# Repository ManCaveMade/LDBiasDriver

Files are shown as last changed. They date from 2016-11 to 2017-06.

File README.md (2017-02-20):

## LDBiasDriver
Copyright Mitchell A. Cox (mitch@enox.co.za)

If you use this design, please acknowledge me in any resulting publications.

### What is it?

1. A low noise laser diode bias driver which uses the ThorLabs MLD203P1 constant power and also the MLD203CLN constanct current (better for fast modulation systems which use a Bias-Tee) bias driver. https://www.thorlabs.com/thorproduct.cfm?partnumber=MLD203P1 and https://www.thorlabs.com/thorproduct.cfm?partnumber=MLD203CLN

2. An Arduino based controller for the CC version is WIP. This controller will allow greater than 12 bits of control of the output current as well as digital monitoring of the actual current, etc. I also plan on creating a user friendly MATLAB GUI for it.

#### Features

* Input voltage: 6 - 18 V
* Output current: < 200 mA @ 3.0 V
* Laser current monitor output: 0.1V/mA wrt. GND (can be changed by changing resistors on op-amp)
* Over current protection resistor (R3)
* Sexy red power on LED
* Compact
* SMA for DC bias output (easy connection direct to Bias-Tee)
* ~3 uA noise
 
Designed with Eagle 7.7

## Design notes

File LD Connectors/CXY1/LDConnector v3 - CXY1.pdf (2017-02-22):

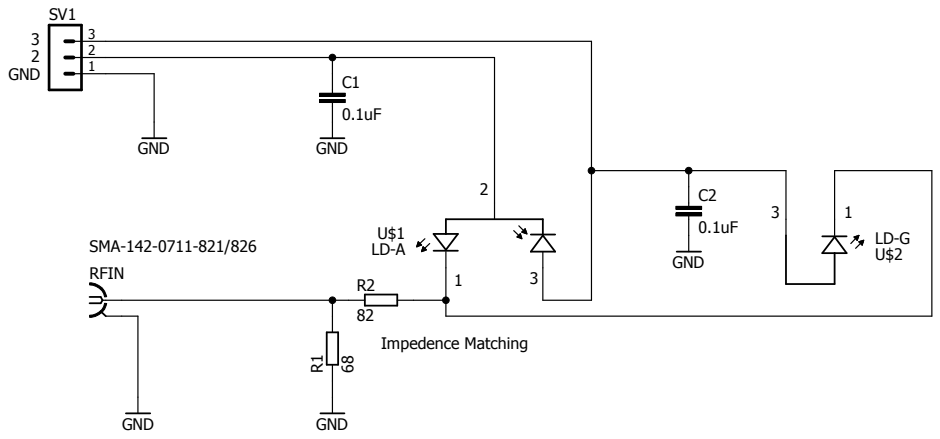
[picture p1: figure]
GND; SMA-142-0711-821/826; GND ⁶⁸; GND RFIN; Impedence Matching

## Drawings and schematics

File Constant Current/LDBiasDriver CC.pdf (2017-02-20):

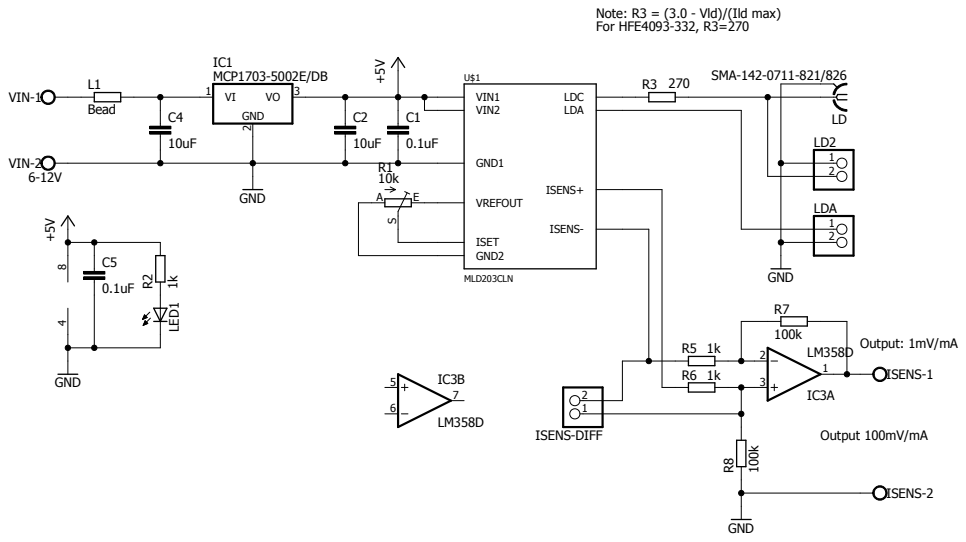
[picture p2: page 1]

Note: R3 = (3.0 - Vld)/(Ild max)
For HFE4093-332, R3=270

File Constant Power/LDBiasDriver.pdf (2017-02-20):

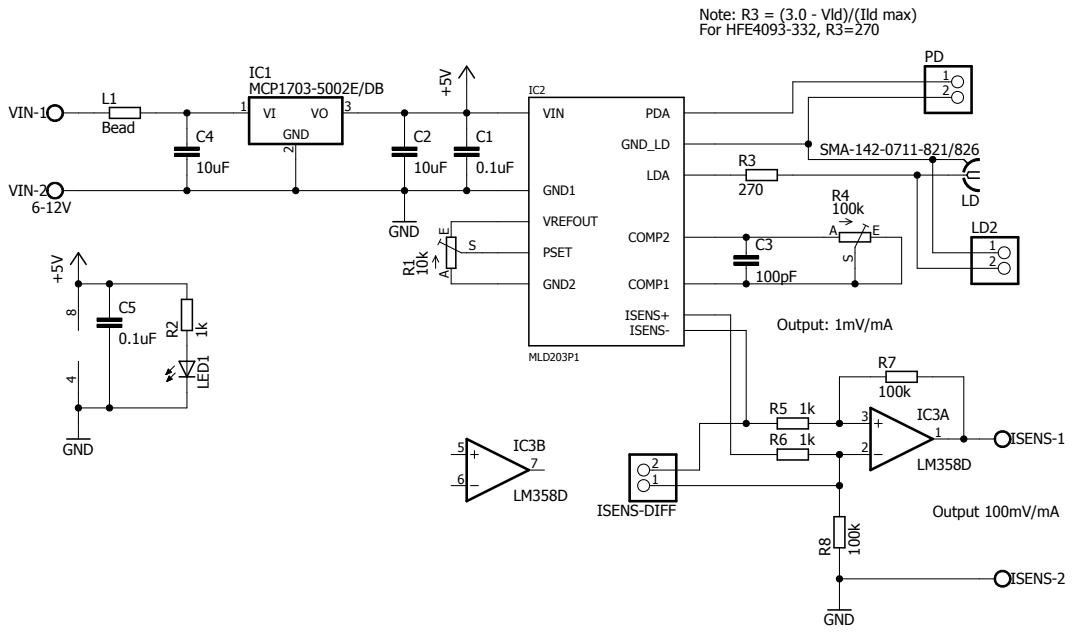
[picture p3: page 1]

Note: R3 = (3.0 - Vld)/(Ild max)
For HFE4093-332, R3=270

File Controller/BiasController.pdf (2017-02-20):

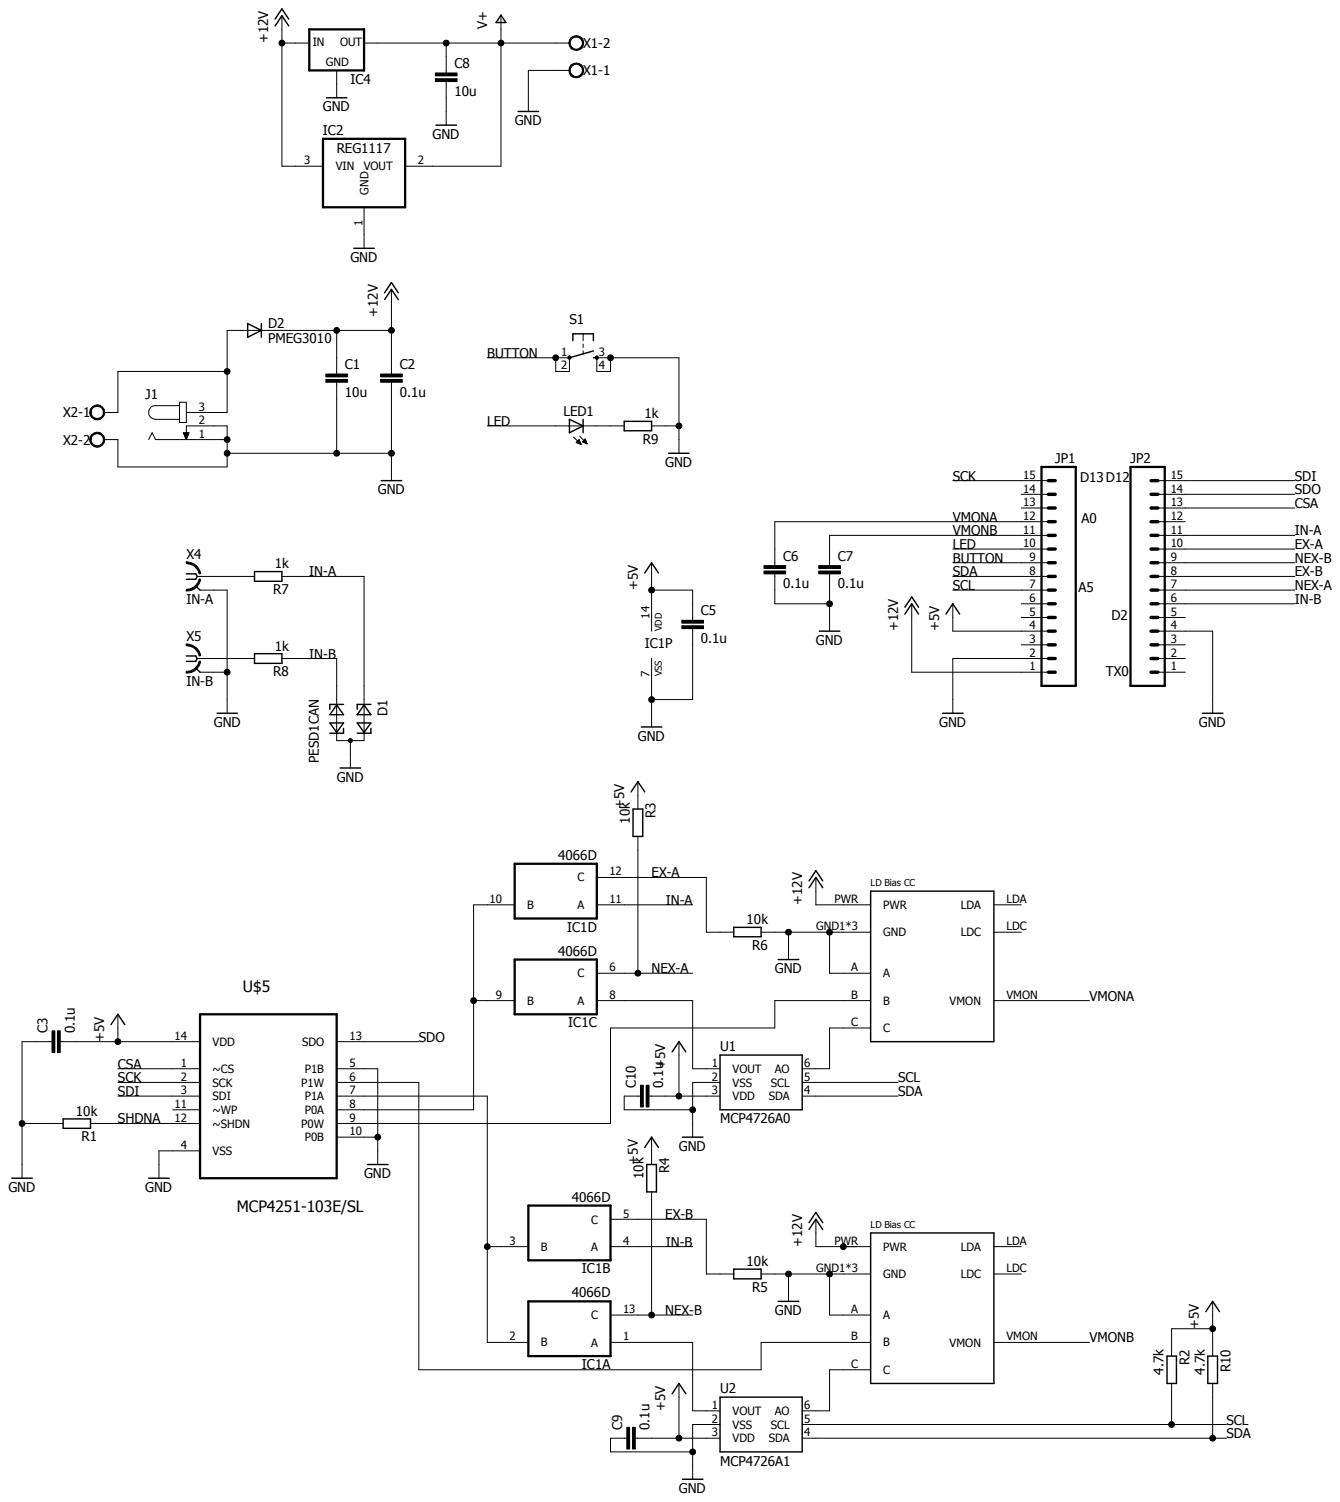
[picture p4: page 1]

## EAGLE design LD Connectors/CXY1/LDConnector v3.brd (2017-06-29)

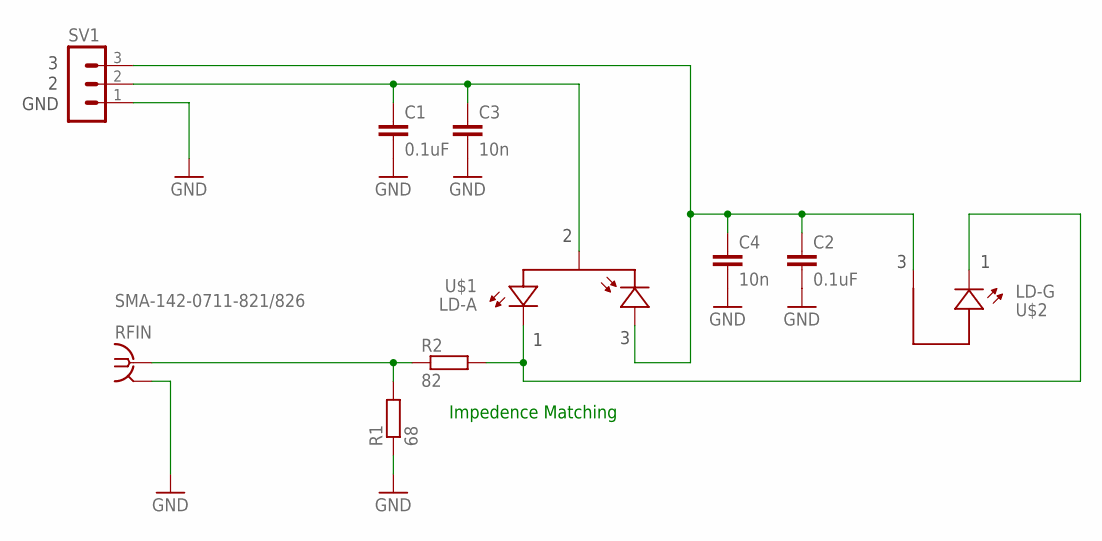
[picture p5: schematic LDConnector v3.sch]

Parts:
C1, C2: 0.1uF; C0603
C3, C4: 10n; C0603
R1: 68; R0603
R2: 82; R0603
RFIN: SMA-142-0711-821/826; J502-ND-142-0711-821/826
SV1: MA03-1
U$1: LD-A; TYPEA
U$2: LD-G; TYPEG

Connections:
GND: C1.2, C2.2, C3.2, C4.2, R1.1, RFIN.G@1 (2), RFIN.G@2 (2), RFIN.G@3 (2), RFIN.G@4 (2), SV1.1
unnamed: C1.1, C3.1, SV1.2, U$1.2-PDC-LDA (LDA-PDC)
unnamed: R2.2, U$1.1-LDC (LDC), U$2.1-LDC (LDC)
unnamed: R1.2, R2.1, RFIN.1
unnamed: C2.1, C4.1, SV1.3, U$1.3-PDA (PDA), U$2.3-LDA (LDA)

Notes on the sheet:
Impedence Matching
GND

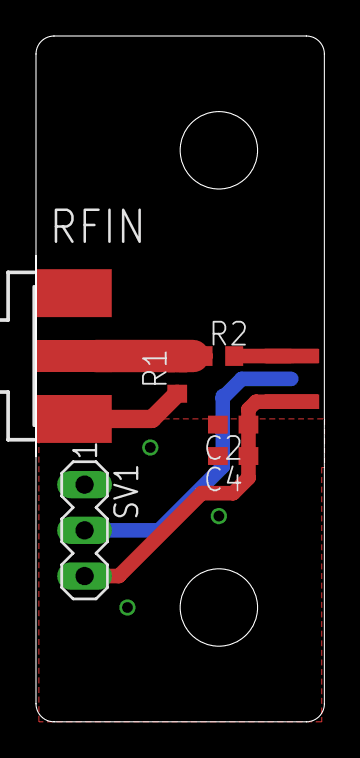
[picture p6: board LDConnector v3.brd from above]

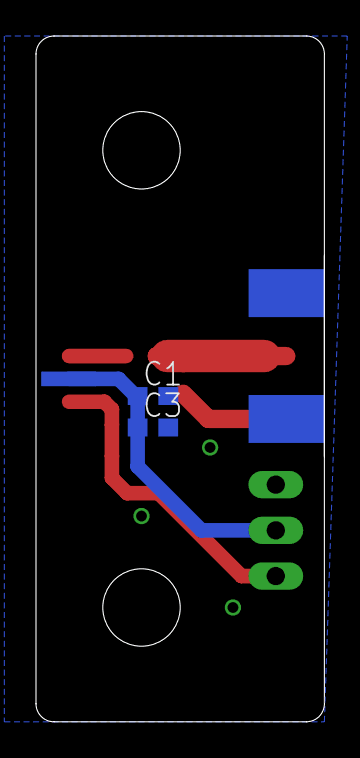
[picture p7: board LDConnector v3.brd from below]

Board: 2 copper layers, 16.0 x 38.1 mm, 10 parts (2 on the bottom side), 5 nets.

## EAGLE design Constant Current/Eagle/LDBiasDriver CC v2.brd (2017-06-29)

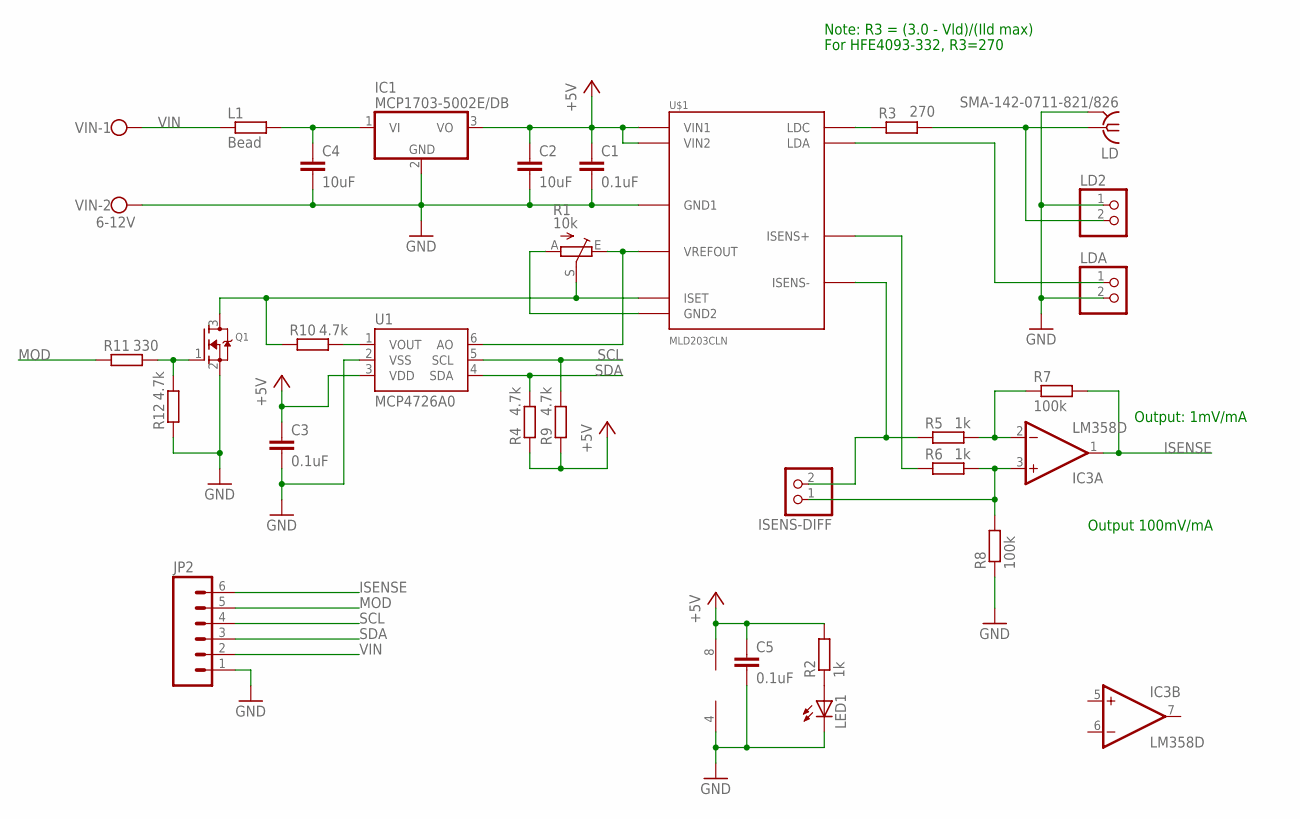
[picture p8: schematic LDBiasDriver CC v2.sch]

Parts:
C1, C3, C5: 0.1uF; C0805
C2, C4: 10uF; C0805
IC1: MCP1703-5002E/DB; SOT223
IC3: LM358D; SO08
ISENS-DIFF: PINHD-1X2; 1X02
JP2: M06POLAR_LOCK; MOLEX-1X6_LOCK
L1: Bead; R0805
LD: SMA-142-0711-821/826; J502-ND-142-0711-821/826
LD2: PINHD-1X2; 1X02
LDA: PINHD-1X2; 1X02
LED1: LEDCHIPLED_1206; CHIPLED_1206
Q1: MOSFET-NREFLOW; SOT23
R1: 10k; RJ9W
R2, R5, R6: 1k; R0805
R3: 270; R0805
R4, R9, R10, R12: 4.7k; R0805
R7, R8: 100k; R0805
R11: 330; R0805
U1: MCP4726A0; SOT23-6
U$1: MLD203CLN; MLD203
VIN: 6-12V; W237-102

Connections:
+5V: C1.1, C2.1, C3.1, C5.1, IC1.3 (VO), IC3.8 (V+), R2.2, R4.1, R9.1, U1.3 (VDD), U$1.P$1 (VIN1), U$1.P$2 (VIN2)
GND: C1.2, C2.2, C3.2, C4.2, C5.2, IC1.2 (GND), IC3.4 (V-), JP2.1, LD.G@1 (2), LD.G@2 (2), LD.G@3 (2), LD.G@4 (2), LD2.1, LDA.2, LED1.C, Q1.2 (S), R8.1, R12.1, U1.2 (VSS), U$1.P$3 (GND1), VIN.2
ISENSE: IC3.1 (OUT), JP2.6, R7.2
MOD: JP2.5, R11.1
unnamed: R1.E, U1.6 (AO), U$1.P$5 (VREFOUT)
unnamed: LED1.A, R2.1
unnamed: Q1.3 (D), R1.S, R10.1, U$1.P$6 (ISET)
unnamed: R1.A, U$1.P$4 (GND2)
unnamed: R6.1, U$1.P$12 (ISENS+)
unnamed: ISENS-DIFF.2, R5.1, U$1.P$13 (ISENS-)
unnamed: LD.1, LD2.2, R3.2
unnamed: R3.1, U$1.P$11 (LDC)
unnamed: Q1.1 (G), R11.2, R12.2
unnamed: LDA.1, U$1.P$14 (LDA)
unnamed: R10.2, U1.1 (VOUT)
unnamed: C4.1, IC1.1 (VI), L1.2
unnamed: IC3.2 (-IN), R5.2, R7.1
unnamed: IC3.3 (+IN), ISENS-DIFF.1, R6.2, R8.2
SCL: JP2.4, R9.2, U1.5 (SCL)
SDA: JP2.3, R4.2, U1.4 (SDA)
VIN: JP2.2, L1.1, VIN.1

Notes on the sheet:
Note: R3 = (3.0 - Vld)/(Ild max)
For HFE4093-332, R3=270
Output: 1mV/mA
Output 100mV/mA

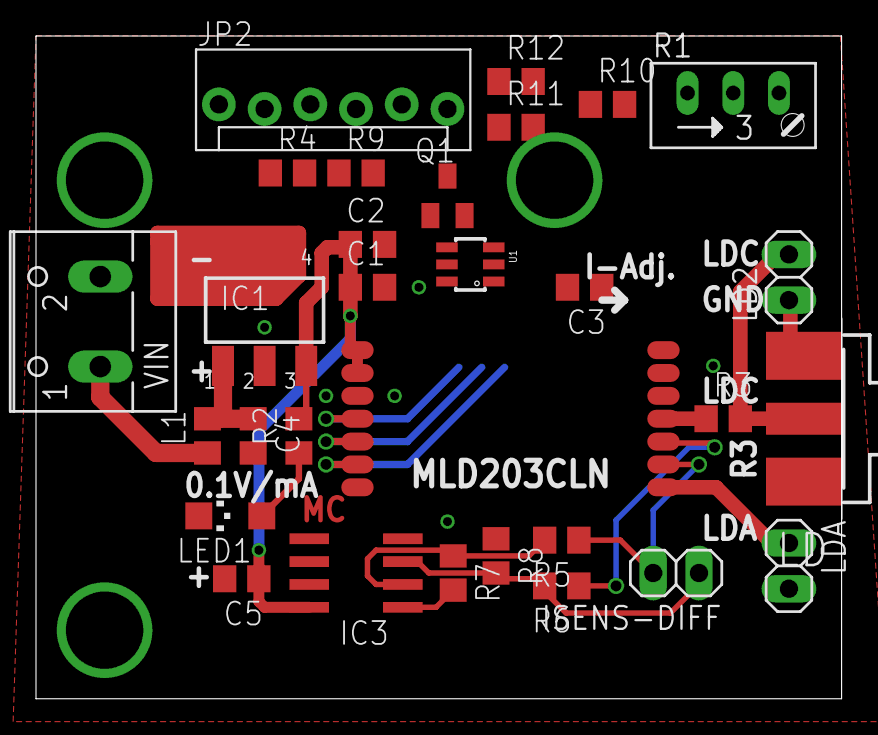
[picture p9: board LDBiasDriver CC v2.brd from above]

Board: 2 copper layers, 44.8 x 36.8 mm, 30 parts (0 on the bottom side), 21 nets.

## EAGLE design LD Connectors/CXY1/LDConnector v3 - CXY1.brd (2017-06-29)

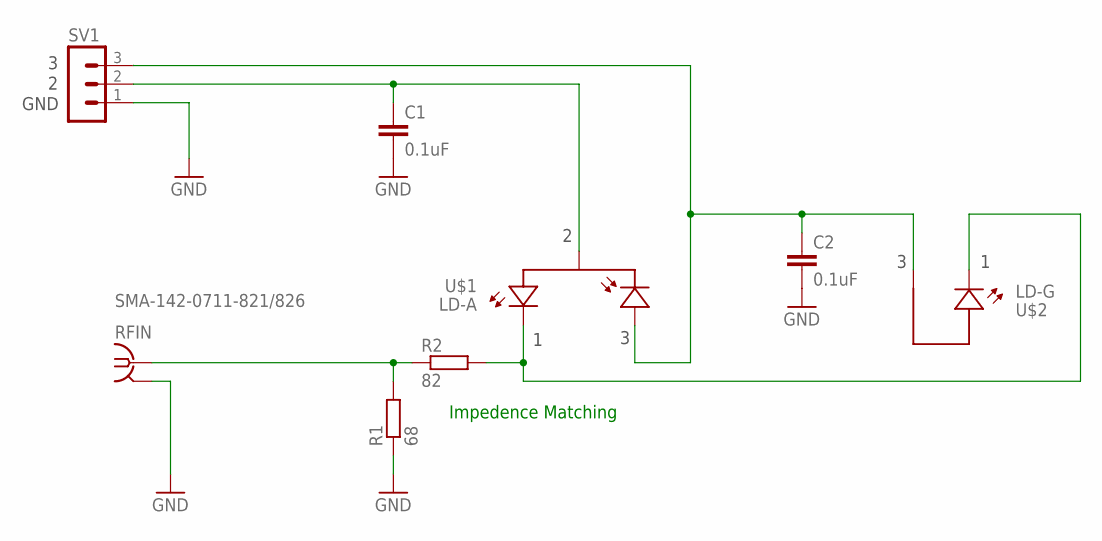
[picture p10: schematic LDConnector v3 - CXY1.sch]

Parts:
C1, C2: 0.1uF; C0603
R1: 68; R0603
R2: 82; R0603
RFIN: SMA-142-0711-821/826; J502-ND-142-0711-821/826
SV1: MA03-1
U$1: LD-A; TYPEA
U$2: LD-G; TYPEG

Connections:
GND: C1.2, C2.2, R1.1, RFIN.G@1 (2), RFIN.G@2 (2), RFIN.G@3 (2), RFIN.G@4 (2), SV1.1
unnamed: C1.1, SV1.2, U$1.2-PDC-LDA (LDA-PDC)
unnamed: R2.2, U$1.1-LDC (LDC), U$2.1-LDC (LDC)
unnamed: R1.2, R2.1, RFIN.1
unnamed: C2.1, SV1.3, U$1.3-PDA (PDA), U$2.3-LDA (LDA)

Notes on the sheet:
Impedence Matching
GND

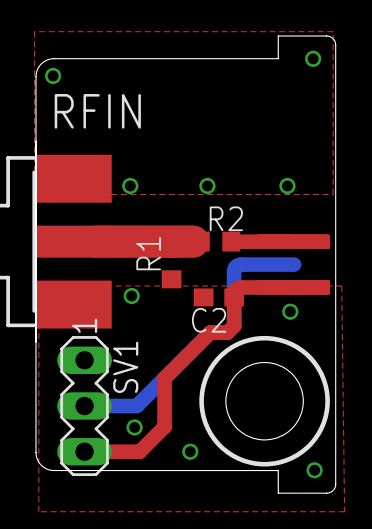
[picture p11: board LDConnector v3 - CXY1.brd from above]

Board: 2 copper layers, 16.6 x 25.4 mm, 8 parts (1 on the bottom side), 5 nets.

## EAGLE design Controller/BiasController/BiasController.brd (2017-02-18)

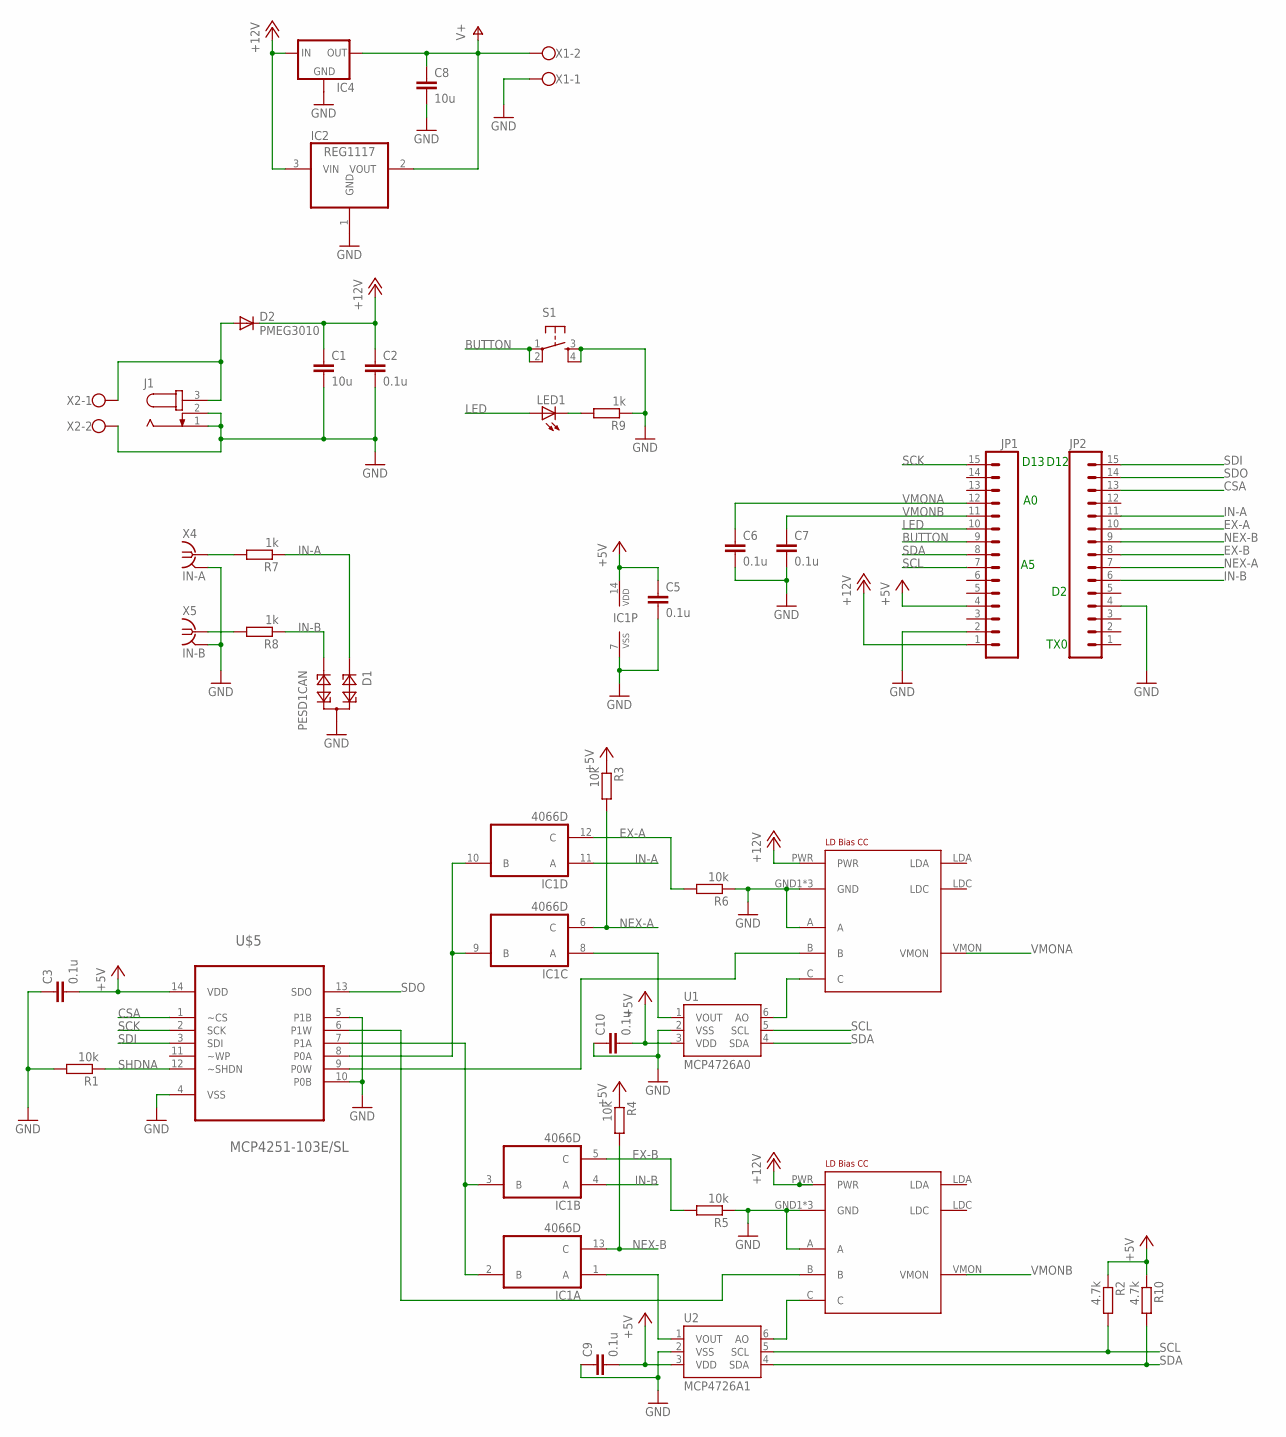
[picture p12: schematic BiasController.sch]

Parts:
C1, C8: 10u; C0805
C2, C3, C5, C6, C7, C9, C10: 0.1u; C0805
D1: PESD1CAN; SOT23
D2: PMEG3010; SOD-323
IC1: 4066D; SO14
IC2: REG1117; SOT223
IC4: 78XXS
J1: JACK-PLUG0; SPC4077
JP1, JP2: M15LOCK_LONGPADS; 1X15_LOCK_LONGPADS
LED1: LED0603; LED-0603
R1, R3, R4, R5, R6: 10k; R0805
R2, R10: 4.7k; R0805
R7, R8, R9: 1k; R0805
S1: TAC_SWITCHPTH; TACTILE-PTH
U1: MCP4726A0; SOT23-6
U2: MCP4726A1; SOT23-6
U$1, U$2: LDBIASCC; LDBIASDRIVERCC
U$5: MCP4251-103E/SL; SOIC127P600X175-14N
X1, X2: W237-102
X4: IN-A; J502-ND-142-0711-821/826
X5: IN-B; J502-ND-142-0711-821/826

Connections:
+5V: C3.2, C5.1, C9.2, C10.2, IC1.14 (VDD), JP1.4, R2.1, R3.1, R4.1, R10.1, U1.3 (VDD), U2.3 (VDD), U$5.14 (VDD)
+12V: C1.1, C2.1, D2.1 (C), IC2.3 (VIN), IC4.IN, JP1.1, U$1.PWR, U$2.PWR
BUTTON: JP1.9, S1.1, S1.2
CSA: JP2.13, U$5.1 (~CS)
EX-A: IC1.12 (C), JP2.10, R6.2
EX-B: IC1.5 (C), JP2.8, R5.2
GND: C1.2, C2.2, C3.1, C5.2, C6.2, C7.2, C8.2, C9.1, C10.1, D1.3, IC1.7 (VSS), IC2.1 (GND), IC4.GND, J1.1, J1.2, JP1.2, JP2.4, R1.2, R5.1, R6.1, R9.1, S1.3, S1.4, U1.2 (VSS), U2.2 (VSS), U$1.A, U$1.GND1 (GND), U$1.GND2 (GND), U$1.GND3 (GND), U$2.A, U$2.GND1 (GND), U$2.GND2 (GND), U$2.GND3 (GND), U$5.4 (VSS), U$5.5 (P1B), U$5.10 (P0B), X1.1, X2.2, X4.G@1 (2), X4.G@2 (2), X4.G@3 (2), X4.G@4 (2), X5.G@1 (2), X5.G@2 (2), X5.G@3 (2), X5.G@4 (2)
IN-A: D1.1, IC1.11 (A), JP2.11, R7.1
IN-B: D1.2, IC1.4 (A), JP2.6, R8.1
LED: JP1.10, LED1.A
unnamed: U1.6 (AO), U$1.C
unnamed: IC1.8 (A), U1.1 (VOUT)
unnamed: U$1.B, U$5.9 (P0W)
unnamed: IC1.9 (B), IC1.10 (B), U$5.8 (P0A)
unnamed: IC1.2 (B), IC1.3 (B), U$5.7 (P1A)
unnamed: U2.6 (AO), U$2.C
unnamed: D2.2 (A), J1.3, X2.1
unnamed: LED1.C, R9.2
unnamed: R7.2, X4.1
unnamed: R8.2, X5.1
unnamed: IC1.1 (A), U2.1 (VOUT)
unnamed: U$2.B, U$5.6 (P1W)
NEX-A: IC1.6 (C), JP2.7, R3.2
NEX-B: IC1.13 (C), JP2.9, R4.2
SCK: JP1.15, U$5.2 (SCK)
SCL: JP1.7, R2.2, U1.5 (SCL), U2.5 (SCL)
SDA: JP1.8, R10.2, U1.4 (SDA), U2.4 (SDA)
SDI: JP2.15, U$5.3 (SDI)
SDO: JP2.14, U$5.13 (SDO)
SHDNA: R1.1, U$5.12 (~SHDN)
V+: C8.1, IC2.2 (VOUT), IC4.OUT, X1.2
VMONA: C6.1, JP1.12, U$1.VMON
VMONB: C7.1, JP1.11, U$2.VMON

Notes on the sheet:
D13
D12
TX0

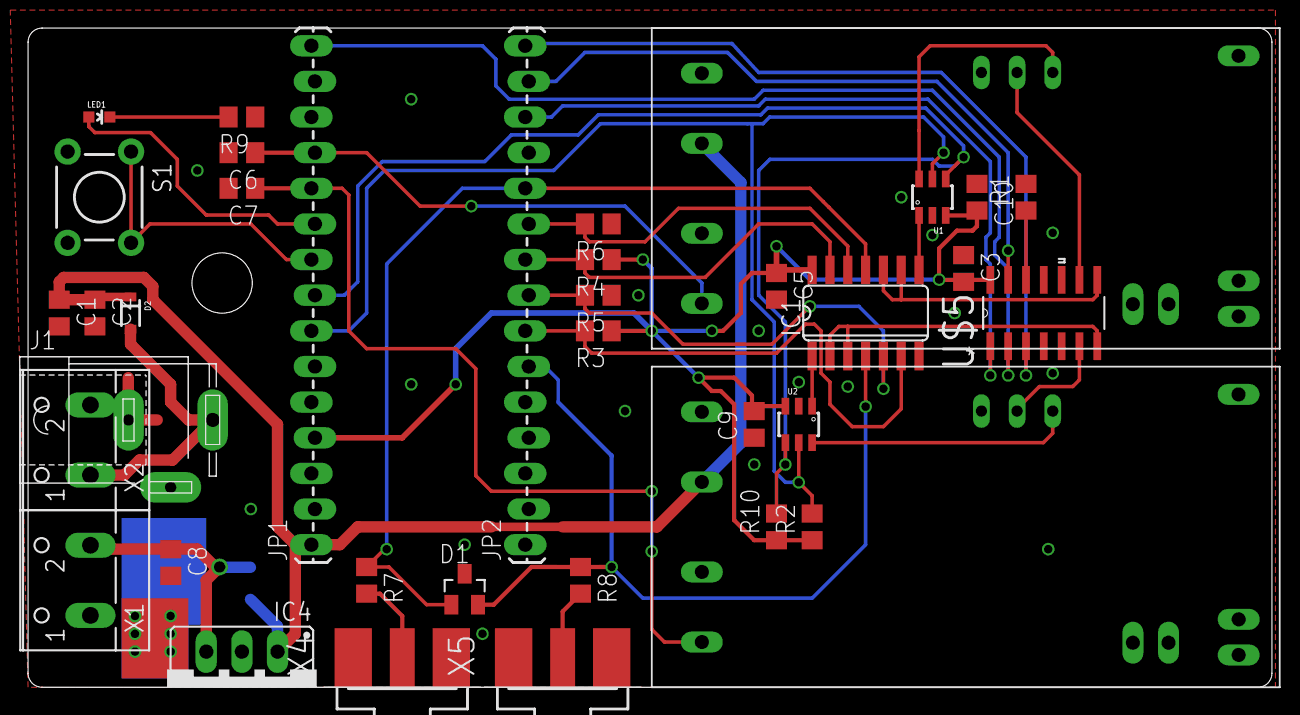
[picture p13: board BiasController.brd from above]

Board: 2 copper layers, 88.7 x 47.0 mm, 38 parts (1 on the bottom side), 33 nets.

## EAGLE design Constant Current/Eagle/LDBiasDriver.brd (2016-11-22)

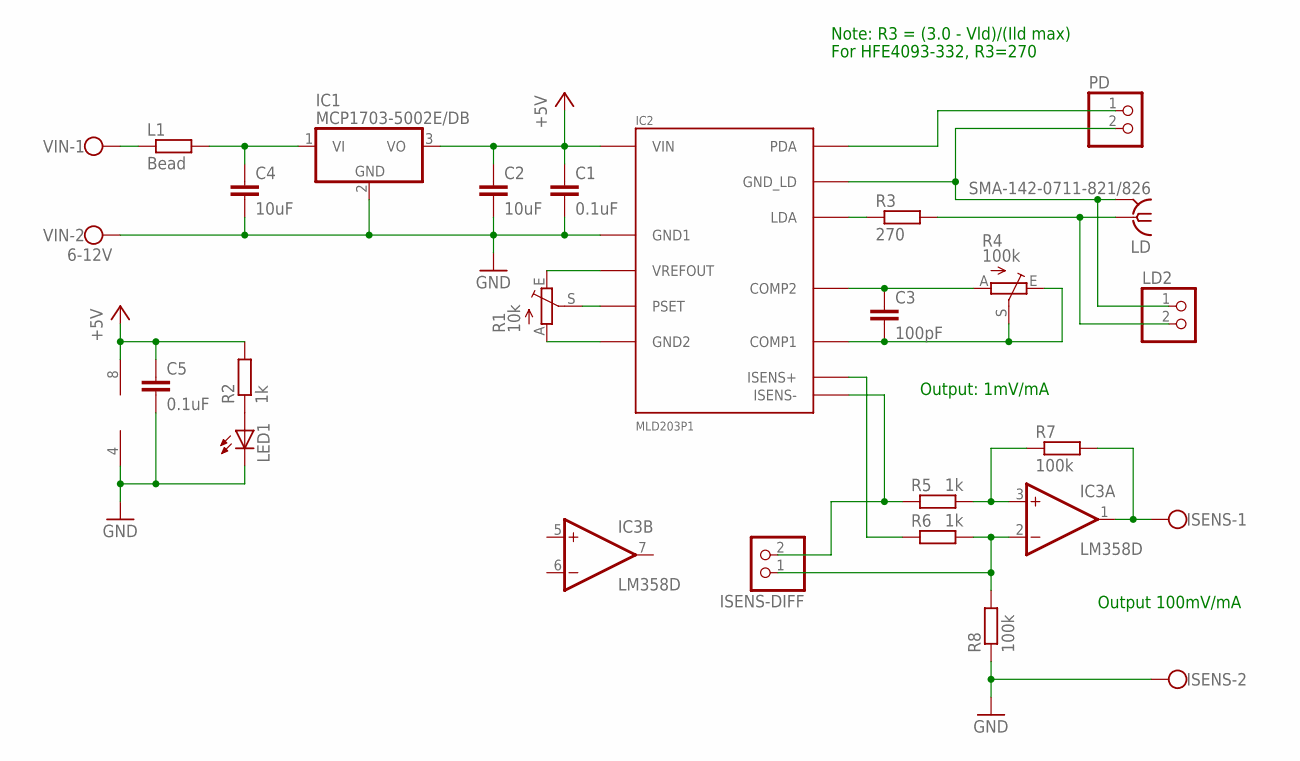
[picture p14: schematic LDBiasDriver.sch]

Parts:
C1, C5: 0.1uF; C0805
C2, C4: 10uF; C0805
C3: 100pF; C0805
IC1: MCP1703-5002E/DB; SOT223
IC2: MLD203P1; MLD203
IC3: LM358D; SO08
ISENS: W237-102
ISENS-DIFF: PINHD-1X2; 1X02
L1: Bead; R0805
LD: SMA-142-0711-821/826; J502-ND-142-0711-821/826
LD2: PINHD-1X2; 1X02
LED1: LEDCHIPLED_1206; CHIPLED_1206
PD: PINHD-1X2; 1X02
R1: 10k; RJ9W
R2, R5, R6: 1k; R0805
R3: 270; R0805
R4: 100k; RJ9W
R7, R8: 100k; R0805
VIN: 6-12V; W237-102

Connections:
+5V: C1.1, C2.1, C5.1, IC1.3 (VO), IC2.P$1 (VIN), IC2.P$2 (VIN), IC3.8 (V+), R2.2
GND: C1.2, C2.2, C4.2, C5.2, IC1.2 (GND), IC2.P$3 (GND1), IC3.4 (V-), ISENS.2, LED1.C, R8.1, VIN.2
unnamed: IC2.P$6 (PSET), R1.S
unnamed: LED1.A, R2.1
unnamed: IC2.P$5 (VREFOUT), R1.E
unnamed: IC2.P$4 (GND2), R1.A
unnamed: IC2.P$12 (ISENS+), R6.1
unnamed: IC2.P$13 (ISENS-), ISENS-DIFF.2, R5.1
unnamed: LD.1, LD2.2, R3.2
unnamed: IC2.P$14 (LDA), R3.1
unnamed: IC2.P$11 (GND_LD), LD.G@1 (2), LD.G@2 (2), LD.G@3 (2), LD.G@4 (2), LD2.1, PD.2
unnamed: IC2.P$8 (PDA), PD.1
unnamed: C3.2, IC2.P$10 (COMP1), R4.E, R4.S
unnamed: C3.1, IC2.P$9 (COMP2), R4.A
unnamed: L1.1, VIN.1
unnamed: C4.1, IC1.1 (VI), L1.2
unnamed: IC3.3 (+IN), R5.2, R7.1
unnamed: IC3.2 (-IN), ISENS-DIFF.1, R6.2, R8.2
unnamed: IC3.1 (OUT), ISENS.1, R7.2

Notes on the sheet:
Note: R3 = (3.0 - Vld)/(Ild max)
For HFE4093-332, R3=270
Output: 1mV/mA
Output 100mV/mA

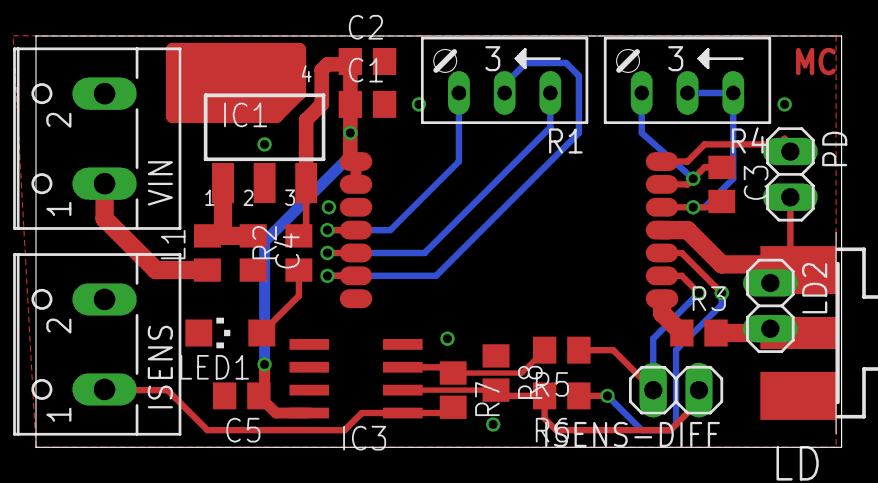
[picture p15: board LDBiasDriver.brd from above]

Board: 2 copper layers, 44.8 x 22.9 mm, 24 parts (0 on the bottom side), 19 nets.

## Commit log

2016-11-06 initial commit for v1.0
    [LDBiasDriver.brd, LDBiasDriver.sch]
2016-11-06 v1.1 WIP with enhancements: > documentation on the PCB > removed stop on some vias for easier adjustement > added holes in case SMA connector not used
    [LDBiasDriver.brd]
2016-11-06 used a standard connector spacing for the SMA alternative.
    [LDBiasDriver.brd, LDBiasDriver.sch]
2016-11-22 Updates based on experience
    [LDBiasDriver.brd, LDBiasDriver.sch]
2016-11-29 Changed directory structure to have separate CC and CP versions
    [LDBiasDriver.brd, LDBiasDriver.sch]
2016-11-29 Added a CC version
    [LDBiasDriver CC.brd, LDBiasDriver CC.sch]
2017-02-05 added controller
    [BiasController.brd, BiasController.sch, LDBiasDriver CC.brd]
2017-02-06 controller done but going to change
    [BiasController.brd, BiasController.sch]
2017-02-18 final version as manufactured
    [BiasController.brd, BiasController.sch]
2017-02-22 added LDConnector board to fit into a ThorLabs CXY1 (or other SM1) holder.
    [LDConnector v2.brd, LDConnector v2.sch, LDConnector v3 - CXY1.brd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]

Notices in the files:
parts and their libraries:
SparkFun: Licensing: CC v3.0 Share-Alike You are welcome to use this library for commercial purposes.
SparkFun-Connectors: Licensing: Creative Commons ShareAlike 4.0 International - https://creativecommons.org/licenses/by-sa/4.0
